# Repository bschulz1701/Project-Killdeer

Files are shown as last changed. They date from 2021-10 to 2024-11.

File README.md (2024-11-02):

# Project-Killdeer
Hardware designs for a LED light string UPS

# Repo Outline
<!-- #### [Documents](Documents/) 

General document and image storage for repo and README -->

#### [Hardware](Hardware/)

Current board files (Eagle), Bill of Materials (BoM), and other design documents

#### [Production](Production/)

Contains the various Gerber and pick and place files required to have the Printed Circuit Boards (PCBs) manufactured or populated 

<!-- #### [Software](Software/)

The software associated with the piece of hardware, this is usually diagnostic software used for verifying or investigating the hardware

#### [Testing](Testing/)

Scripts and results from the testing process and development process. Contains more detailed information about documented issues among other testing.  -->

<!-- ## Overview
* **Type:** Data Logger/Daughterboard 
* **Interfaces:** I<sup>2</sup>C, GPIO, Pulse
* **Release Version:** v0.2 - 2020/07/15 -->

<!-- ![Hyena v0.2 - Top](Documents/Images/Hyena_0v2_Top_Cropped.jpg)

![Hyena v0.2 - Bottom](Documents/Images/Hyena_0v2_Bottom_Cropped.jpg) -->

<!-- ## Features
### On-Board
* Micro SD Card 
* RTC w/Battery Backup
* Temperature/Pressure/RH Sensor
* RGB Ambient Light Sensor
* Reverse Polarity Power Protected Inputs 

### Interface
* Tipping Bucket Input (SPST switch compatible)
* Dedicated Potentiometric Input (x1) 
* Flexible Sensor Inputs (x3)
* Dedicated I<sup>2</sup>C Input (x1) 
* Supports Particle and other Feather based controllers 

## Specifications
* **Sensor Voltage:** 3.3V
* **Sensor Current (Max):** 500mA (Combined)

## Jumper Settings 

**Port Select Jumpers**
| Jumper | Purpose | Position 1 | Position 2 | 
| --- | --- | --- | --- |
| `JP1`	| GPIO vs I<sup>2</sup>C - Port 1 Digital | Select I2C | Select GPIO | 
| `JP2` | GPIO vs I<sup>2</sup>C - Port 1 Analog | Select I2C | Select GPIO | 
| `JP3` | GPIO vs I<sup>2</sup>C - Port 2 Digital | Select I2C | Select GPIO | 
| `JP4` | GPIO vs I<sup>2</sup>C - Port 2 Analog | Select I2C | Select GPIO | 
| `JP5` | GPIO vs I<sup>2</sup>C - Port 3 Digital | Select I2C | Select GPIO | 
| `JP6` | GPIO vs I<sup>2</sup>C - Port 3 Analog | Select I2C | Select GPIO | 
| `JP8` | Power Select (Core vs Ext) - Port 1 | Core Power for Port 1 | External Switched Power for Port 1 |

**Configuration Jumpers**
| Jumper | Purpose | Open | Closed | Default | 
| --- | --- | --- | --- | ----- |
| `JP7` | Enable Hardware WDT | WDT Disabled | WDT Enabled | Closed |  
| `JP9` | Pullup for Port 1 Digital GPIO | Pullup Disabled | Pullup Enabled | Open |
| `JP10` | Gang On-Board and External I2C Buses | I2C Combined | I2C Isolated | Open | 

## Known Issues/Errata

#### WDT Disable

**Issue:** If using Particle Boron as controller and if you have the WDT disabled (leave `JP7` open), the system fails to run properly, or has sporadic resets. This is likely due to parasitic current on the reset line of the Boron.

**Workaround:** Make sure WDT is enabled by closing `JP7`

#### Solder Jumper Stencil

**Issue:** Depending on the thickness of the solder stencil used for populating the board, the solder jumpers may not bridge when desired. This is due to lack of stencil thickness specification and pad geometry.

**Workaround:** Make a note on the board assembly (if working with a board house) as to which jumpers should be connected (see jumper tables). Otherwise, if assembling manually, check the jumpers are connected, and bridge them using solder wire and a soldering iron if they have failed to jump where desired. 
 -->

## Specifications (3S1P)
* Input Voltage (DC Input): 9V ~ 12V
* Input Current (DC Input): 250mA, min
* Low Battery Indication: 2.48V (~ 0.825V/Cell)

**Quiescent Current Values**
| Battery | DC Input | System State | Low Battery | Current Battery | Current DC Input |
| --- | --- | --- | --- | --- | --- |
| 4.5V | 0V | Off | NO | 3.25&mu;A | 0A |
| 4.5V | 0V | On | NO | 4.35&mu;A | 0A |
| 4.5V | 9V | Off | NO | 2.22&mu;A | 10.67mA |
| 4.5V | 9V | On | NO | 2.69&mu;A | 10.67mA |  
| 2V | 9V | Off | YES | 0.97&mu;A| 10.98mA | 
| 2V | 9V | On | YES | 1.42&mu;A | 10.98mA |

## Known Issues/Errata
**3S1P, v0.0:**
* Silkscreen above DC input plug lists voltage range as "5V ~ 12V", if input is less than 7.5V, full output voltage will not be achieved 
* If battery voltage falls below ~ 2V (~ 0.65V/Cell) **and** there is no DC input, the low battery light will not iluminate

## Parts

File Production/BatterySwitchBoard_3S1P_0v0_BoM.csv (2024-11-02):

Qty | Value | Device | Package | Parts | Description | DIGIKEY | DISP | MF | MPN | VALUE | VALUE_PART
1 |  | CONN_023.5MM_ROUND_RESTRICT | SCREWTERMINAL-3.5MM-2_ROUND_RESTRICT | J2 | Genaric 2 terminal header | ED2635-ND |  | On Shore | OSTTE020161
4 |  | MOUNTING_HOLE4_NP | 4_40 | H1, H2, H3, H4 | Genaric Mechanical Mounting Hole | DNP |  | N/A | DNP
1 |  | SN74AUP1G14DCK | DCK_R-PDSO-G5 | U3 | SN74x1G14 - Single Schmitt Triger Inverter | 296-19076-1-ND |  | TI | SN74AUP1G14DCKR
1 | 0.1uF | C-EU0.1UFC0603 | C0603 | C5 | CAPACITOR, European symbol | 490-6051-1-ND |  | Murata | GCM188R71E104KA57D
1 | 10k | R-EU_10KR0603 | R0603 | R4 | RESISTOR, European symbol | 311-10.0KHRCT-ND |  | Yageo | RC0603FR-0710KL |  | 10k
2 | 10uF | C-EU10UFC0805 | C0805 | C3, C4 | CAPACITOR, European symbol | 490-6473-6-ND |  | Murata | GRM21BR61C106KE15K
1 | 2.2uH | INDUCTOR1008 | 1008 | L1 | Genaric inductor
1 | 220k | R-EU_220KR0603 | R0603 | R3 | RESISTOR, European symbol | 311-220KHRCT-ND |  | Yageo | RC0603FR-07220KL |  | 220k
2 | 22uF | C-EU22UFC0805 | C0805 | C1, C2 | CAPACITOR, European symbol | 490-9952-1-ND |  | Murata | GRM219R61C226ME15L
1 | 33.2k | R-EU_33.2KR0603 | R0603 | R5 | RESISTOR, European symbol | 311-33.2KHRCT-ND |  | Yageo | RC0603FR-0733K2L |  | 33.2k
1 | 4.7k | R-EU_4.7KR0603 | R0603 | R1 | RESISTOR, European symbol | 311-4.70KHRCT-ND |  | Yageo | RC0603FR-074K7L |  | 4.7k
1 | 5.5x2.1mm Barrel | POWER_JACKSMD | POWER_JACK_SMD | J1 | Power Jack Connector | 732-5929-1-ND |  | Wurth | 694106106102 | 5.5x2.1mm Barrel
1 | 750k | R-EU_750KR0603 | R0603 | R2 | RESISTOR, European symbol | 311-750KHRCT-ND |  | Yageo | RC0603FR-07750KL |  | 750k
3 | AACLIP | AACLIP | BAT_AA | BT1, BT2, BT3 | AA Battery Holder/Contact | BK-92-ND |  | MPD | BK-92
1 | DIODE_CCBAT54CSOT23 | DIODE_CCBAT54CSOT23 | SOT23-3 | D1 | Dual Diode, Common Cathode | BAT54CLT1GOSCT-ND |  | ON Semiconductor | BAT54CLT1G
1 | DMG3404 | MOSFET-NCH-DMG3404L | SOT23-3 | Q1 | N-channel MOSFETs | DMG3404L-7DICT-ND |  | Diodes Incorporated | DMG3404L-7 | DMG3404
1 | LED0603 | LED0603 | LED_0603 | D2 | Genaric LED
1 | MIC842L | MIC842L | DCK_R-PDSO-G5 | U7 | Comparator with internal voltage referance (1.24V), 5V and 3.3V compatable, 20mA output current | 576-2927-1-ND |  | Microchip | MIC842LYC5-TR
1 | SN74AUP2G08DCU | SN74AUP2G08DCU | DCU_(S-PDSO-G8) | U4 | SN74AUP2G08 - AND, 2 Element, 2 Input | 296-32271-1-ND |  | TI | SN74AUP2G08DCUR
1 | SPDTOS1020_RT | SPDTOS1020_RT | OS102011MA1QN1 | S1 | Genaric SPDT switch | CKN9559-ND |  | C&K | OS102011MA1QN1
1 | TLV3691DCK | TLV3691DCK | DCK_R-PDSO-G5 | U5 | TLV3691 - Nanopower Analog Comparator | 296-37910-1-ND |  | TI | TLV3691IDCKR
2 | TPS22917DBV | TPS22917DBV | DBV_R-PDSO-G6 | U1, U2 | TPS22917 - Ultra Low Leakage Load Switch | 296-48370-1-ND |  | TI | TPS22917DBVT
1 | TPS56209 | TPS56209 | DDC_R-PDSO-G6 | U6 | TPS563209/TPS562209 - High Efficiency Synchronous Boost Converter | 296-37302-1-ND | TPS562209 | TI | TPS562209DDCT

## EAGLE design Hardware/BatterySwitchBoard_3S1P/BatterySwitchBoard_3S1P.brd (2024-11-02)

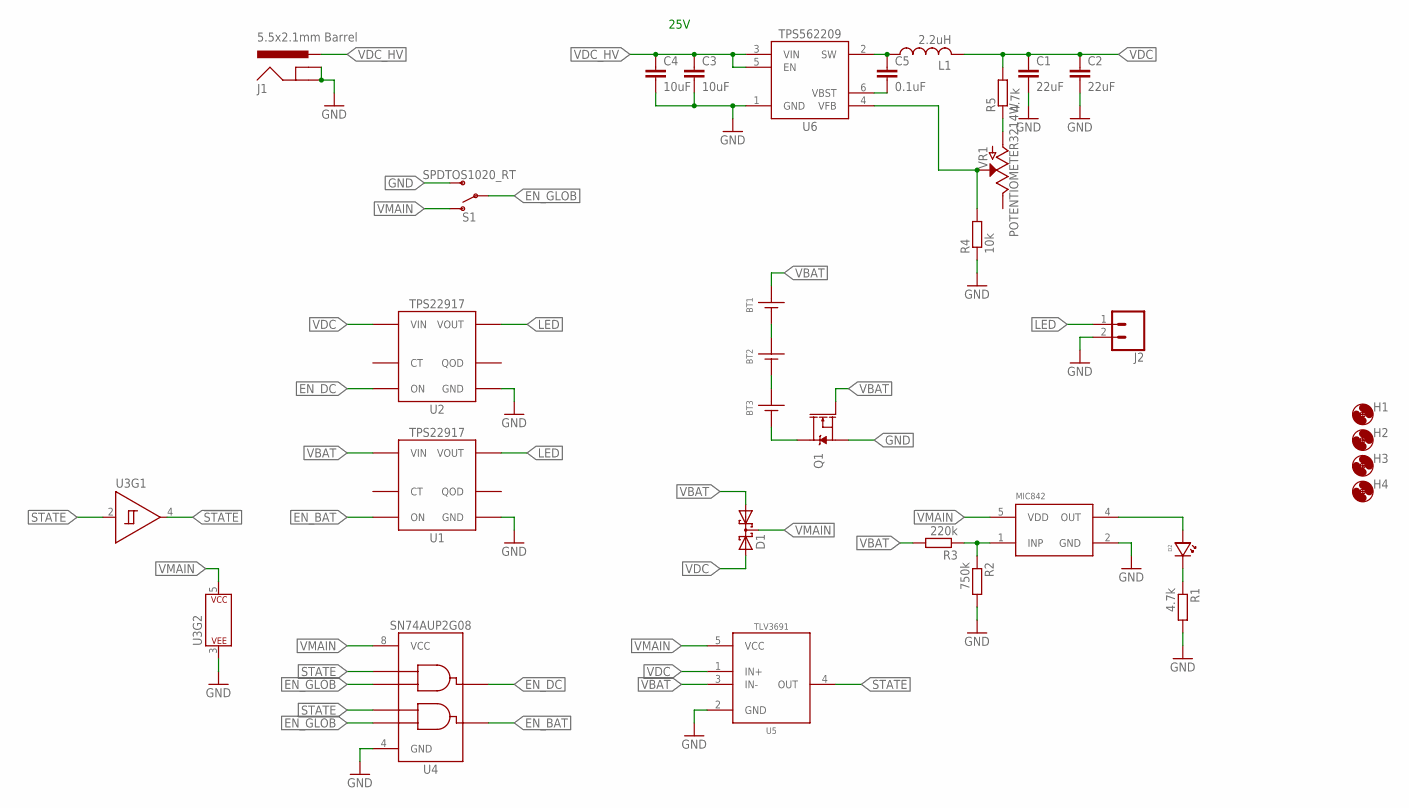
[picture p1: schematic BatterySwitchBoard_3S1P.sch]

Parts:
BT1, BT2, BT3: AACLIP; BAT_AA
C1, C2: 22uF; C0805
C3, C4: 10uF; C0805
C5: 0.1uF; C0603
D1: DIODE_CCBAT54CSOT23; SOT23-3
D2: LED0603; LED_0603
H1, H2, H3, H4: MOUNTING_HOLE4_NP; 4_40
J1: 5.5x2.1mm Barrel; POWER_JACK_SMD
J2: CONN_023.5MM_ROUND_RESTRICT; SCREWTERMINAL-3.5MM-2_ROUND_RESTRICT
L1: 2.2uH; 1008
Q1: DMG3404; SOT23-3
R1, R5: 4.7k; R0603
R2: 750k; R0603
R3: 220k; R0603
R4: 10k; R0603
S1: SPDTOS1020_RT; OS102011MA1QN1
U1, U2: TPS22917DBV; DBV_R-PDSO-G6
U3: SN74AUP1G14DCK; DCK_R-PDSO-G5
U4: SN74AUP2G08DCU; DCU_(S-PDSO-G8)
U5: TLV3691DCK; DCK_R-PDSO-G5
U6: TPS56209; DDC_R-PDSO-G6
U7: MIC842L; DCK_R-PDSO-G5
VR1: POTENTIOMETER3214W; POT_3214W

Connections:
!STATE: U3.4 (Y), U4.5 (A2)
EN_BAT: U1.3 (ON), U4.3 (Y2)
EN_DC: U2.3 (ON), U4.7 (Y1)
EN_GLOB: S1.2, U4.2 (B1), U4.6 (B2)
GND: C1.2, C2.2, C3.2, C4.2, J1.GND (GNDBREAK), J1.P$4 (GND), J2.2, Q1.2 (S), R1.2, R2.2, R4.1, S1.3 (S), U1.2 (GND), U2.2 (GND), U3.3 (P$V-), U4.4 (GND), U5.2 (GND), U6.1 (GND), U7.2 (GND)
LED: J2.1, U1.6 (VOUT), U2.6 (VOUT)
unnamed: BT1.NEG@1 (-), BT1.NEG@2 (-), BT2.POS@1 (+), BT2.POS@2 (+)
unnamed: R2.1, R3.1, U7.1 (INP)
unnamed: BT3.NEG@1 (-), BT3.NEG@2 (-), Q1.3 (D)
unnamed: D2.ANODE, U7.4 (OUT)
unnamed: C5.1, L1.1, U6.2 (SW)
unnamed: D2.CATHODE, R1.1
unnamed: C5.2, U6.6 (VBST)
unnamed: R4.2, U6.4 (VFB), VR1.2 (S)
unnamed: BT2.NEG@1 (-), BT2.NEG@2 (-), BT3.POS@1 (+), BT3.POS@2 (+)
unnamed: R5.1, VR1.1 (A)
QOD: U1.5 (QOD), U2.5 (QOD)
STATE: U3.2 (A), U4.1 (A1), U5.4 (OUT)
VBAT: BT1.POS@1 (+), BT1.POS@2 (+), D1.1 (A1), Q1.1 (G), R3.2, U1.1 (VIN), U5.3 (IN-)
VDC: C1.1, C2.1, D1.2 (A2), L1.2, R5.2, U2.1 (VIN), U5.1 (IN+)
VDC_HV: C3.1, C4.1, J1.VIN0 (PWR), U6.3 (VIN), U6.5 (EN)
VMAIN: D1.3 (C), S1.1 (O), U3.5 (P$V+), U4.8 (VCC), U5.5 (VCC), U7.5 (VDD)

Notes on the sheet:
25V

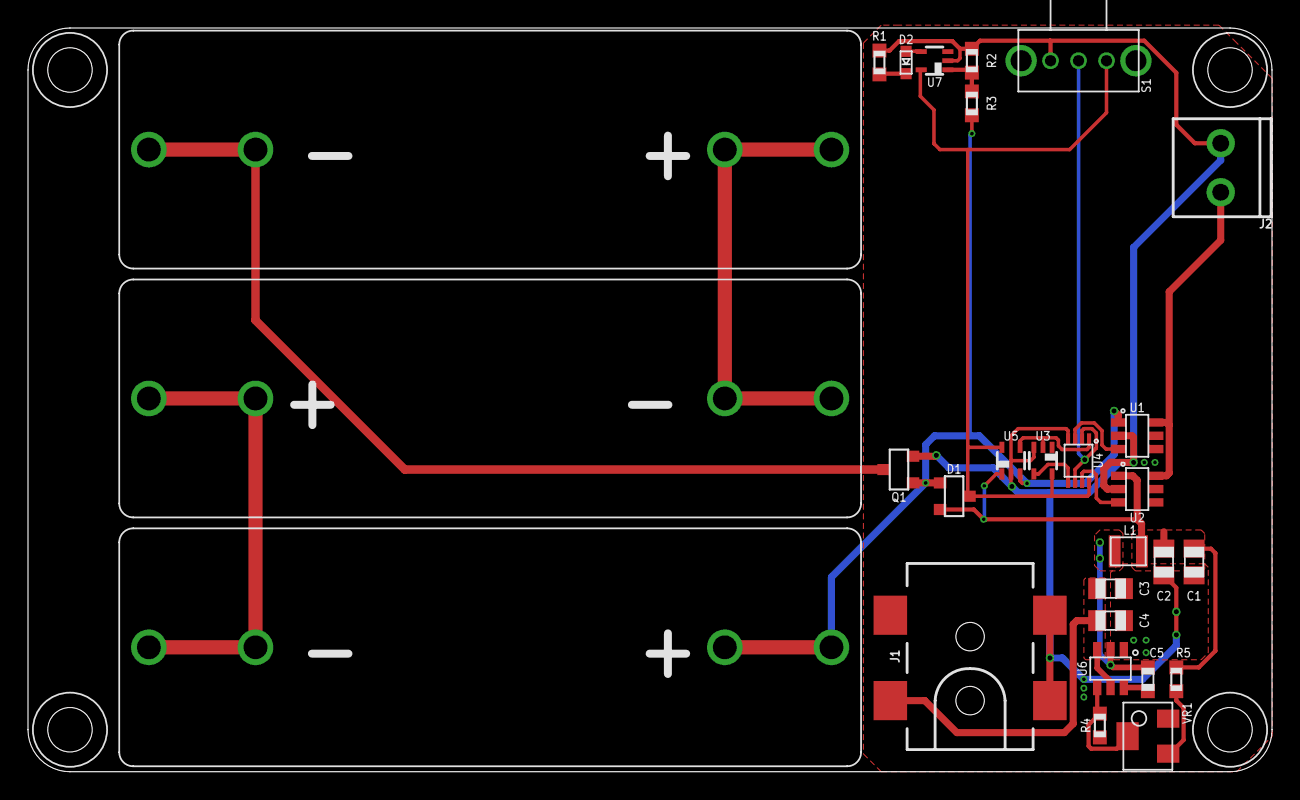
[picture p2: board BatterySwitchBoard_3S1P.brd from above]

Board: 2 copper layers, 88.9 x 53.1 mm, 32 parts (0 on the bottom side), 22 nets.

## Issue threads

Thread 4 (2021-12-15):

Add PWM Support

bschulz1701, 2021-12-15:
## Feature:
Add a knob to allow for PWM dimming

## Important Considerations:
- Low power (if still going to support battery power)
- High frequency - Want to make sure not to have any visible flicker

## Potential Solutions:
- Use a 555 timer to generate a flexible PWM output. This is not ideal for power consumption, but perhaps this version could be wall power only? Might be low enough considering LED output would be 10s of mA - make sure is only drawing current when switched on.
- Use a dedicated fixed frequency oscillator and then control duty cycle with a triangle wave and comparator. Might be able to get better power consumption this way.

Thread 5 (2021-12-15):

Over current indication

bschulz1701, 2021-12-15:
## Feature:
Along with adding adjustable output PWM, add an LED indicator for over-current. Use a CSA and have the current limit dictated by thermal limits most likely - assuming this is still the limiting factor after updated ground plane design. This way if the light is not lit, the device is ensured to work as intended. The current limit indicator would be less than the hard output limit, this way, you would have an indication the working output is being exceeded before the lights shut off.

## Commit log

2021-10-22 Added original Killdeer 2S1P module
    [BatterySwitchBoard_2S1P.brd, BatterySwitchBoard_2S1P.sch]
2021-10-22 Added 3S1P design, sent to fab
    [BatterySwitchBoard_3S1P.brd, BatterySwitchBoard_3S1P.sch]
2024-11-02 Added documentation and minor board updates
    [BatterySwitchBoard_3S1P.brd, BatterySwitchBoard_3S1P.sch, BatterySwitchBoard_3S1P_0v0_BoM.csv]
